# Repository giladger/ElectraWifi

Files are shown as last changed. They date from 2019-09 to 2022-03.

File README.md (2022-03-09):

# ElectraWifi
This project intends to replace a plain Electra AC IR receiver with an ESP8266 to give it wifi capabilities and control it over MQTT.

## Description
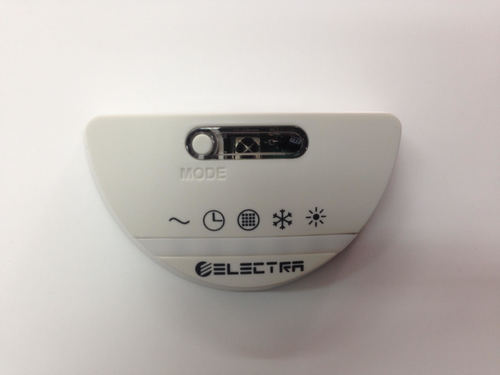
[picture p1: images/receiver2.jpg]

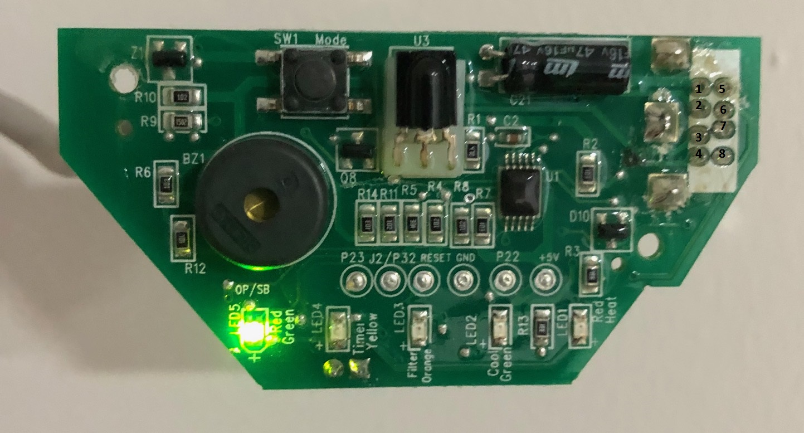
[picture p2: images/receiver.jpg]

The original receiver itself is "dumb" and doesn't hold any state and all the interaction is handled by the main unit, this makes it expandable so it can easily be replaced by an ESP8266.

The receiver is connected to the main unit with an 8-pin mini din connector, with the following pins:

1. 5V
2. Heat LED
3. IR signal
4. Green power LED (LOW for on)
5. Timer LED
6. Beep
7. Button
8. Cool LED

So now all we need to do is throw out the old receiver and hook up an ESP8266 to the pins 1, 3, 4.

## Prerequisites
### Hardware
First you would need:
- ESP8266 (ESP32 would also work)
- 1 NPN transistor
- 2 1kΩ resistors
- A breadboard/PCB
- IR receiver (optional)

Hook everything up according to the following schematic:
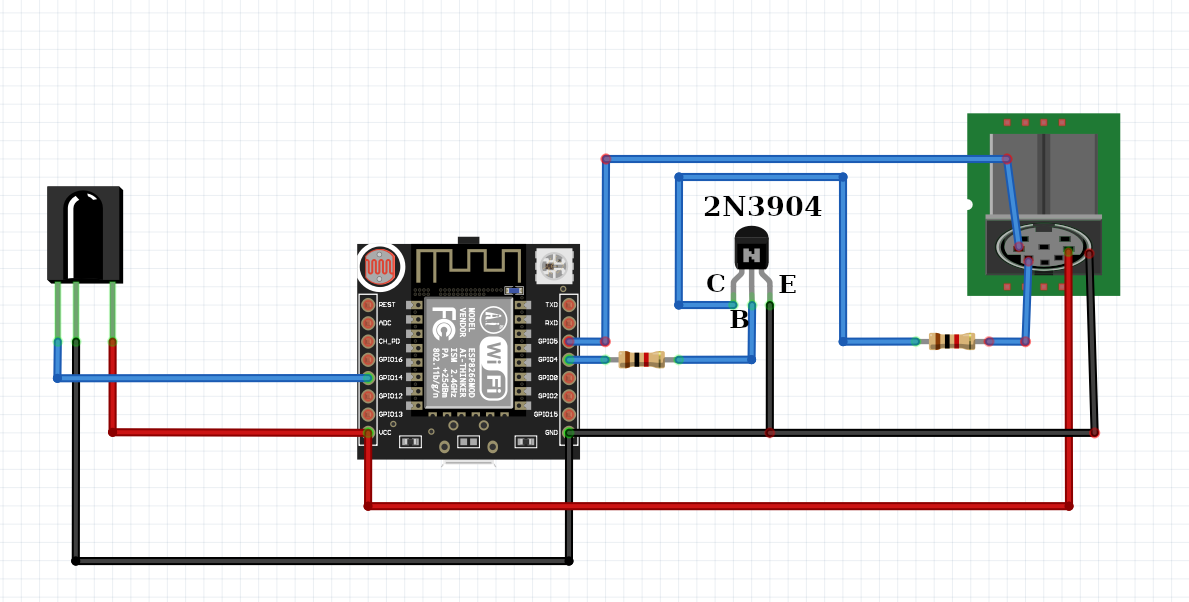
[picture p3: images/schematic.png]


To use the code as-is, use GPIO4 for IR send, GPIO5 for power state input and GPIO14 for IR recv (optional).

### Software
The code in this repo is based on [Homie](https://github.com/homieiot/homie-esp8266) for MQTT handling and for OTA.
Please follow the instructions there to install all the dependencies.

Once the code is installed on the esp, it will boot in configuration mode. Follow the instructions [here](https://homieiot.github.io/homie-esp8266/docs/2.0.0/configuration/json-configuration-file/) to upload a JSON configuration file.

A sample json config file is provided under `/data/homie/config.json`. This file can be edited and uploaded using platform.io under "Platform -> Build Filesystem Image" and the "Platform -> Upload Filesystem Image". Make sure to properly edit the file before uploading.

### Building
Building with platform.io is quite simple. But Homie is not compatible with Platform.io 3.0 for ESP8266 out of the box. You need to change two files in the Homie library.
- Start building as usual. You will see some errors regarding the "HTTPClient" calls not being supported.
- Navigate to the ./pio/libdeps/<target>/Homie/src/Homie/Boot
- Edit the `BootConfig.hpp` and `BootConfig.cpp` files as follows:

- BootConfig.hpp
Add the following line:
```
  WiFiClient _wifiClient;
```
So that the file looks as follows:
```
 private:
  AsyncWebServer _http;
  WiFiClient _wifiClient;
  HTTPClient _httpClient;
  DNSServer _dns;
```

- BootConfig.cpp
Replace the following line:
```
  _httpClient.begin(url);
```
so that it looks as follows:
```
  // send request to destination (as in incoming host header)
  _httpClient.setUserAgent(F("ESP8266-Homie"));
  _httpClient.begin(_wifiClient,url);
  // copy headers
```

## Usage
After the esp is configured, it will subscribe to the following MQTT topics:
- .../state/json/set 
  - This topic accepts a json in the following format (all fields are mandatory), updates the state and send it to the AC unit:   
  `{"power": "on|off", "mode": "cool|heat|fan|dry|auto", "fan": "low|med|high|auto", "temperature": 15..30, "ifeel": "on|off", "swing":"on|off|hor|both"}`
- .../ifeel_temperature/state/set
  - This topic accepts a number between 5 and 36 and sends it to the main unit as a temperature received by the "i feel" function of the remote.
  
Monitoring and getting the real state of the AC is also possible by subscribing to the following topics:
- .../power/state
- .../mode/state
- .../fan/state
- .../temperature/state
- .../ifeel/state
- .../swing/state

### Home Assistant

Home Assistant's MQTT HVAC component can be used with the following configuration:

```yaml
climate:
  - platform: mqtt
    name: AC
    modes:
      - "heat"
      - "cool"
      - "dry"
      - "off"
    fan_modes:
      - "high"
      - "med"
      - "low"
      - "auto"
    swing_modes:
      - "off"
      - "on"
      - "hor"
      - "both"
    min_temp: 16
    max_temp: 30
    power_command_topic: "devices/AC/power/state/set"
    payload_on: "on"
    payload_off: "off"
    mode_command_topic: "devices/AC/mode/state/set"
    mode_state_topic: "devices/AC/mode/state"
    temperature_command_topic: "devices/AC/temperature/state/set"
    temperature_state_topic: "devices/AC/temperature/state"
    fan_mode_command_topic: "devices/AC/fan/state/set"
    fan_mode_state_topic: "devices/AC/fan/state"
    swing_mode_command_topic: "devices/AC/swing/state/set"
    swing_mode_state_topic: "devices/AC/swing/state"
```

It's possible to activate the iFeel by using the build-in aux-heat or away_mode topic for the MQTT HVAC component by adding the following lines:
Its not ideal as it will show "Preset: Home/Away" but it works fine.

```yaml
climate:
    ...
    ...
    away_mode_command_topic: "devices/AC/ifeel/state/set"
    away_mode_state_topic: "devices/AC/ifeel/state"
```

### Home Assistant - Lovelace UI

Lovelace UI example:

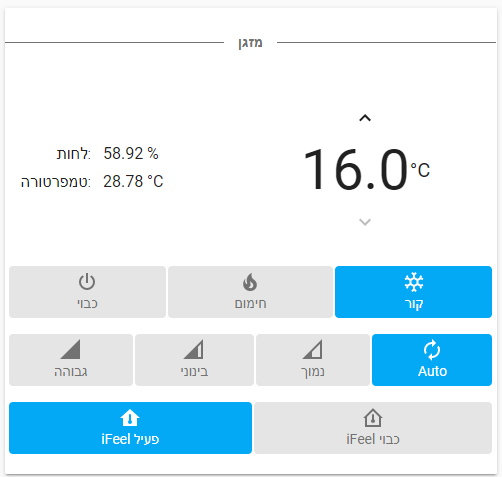
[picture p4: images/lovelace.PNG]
Lovelace UI Example


Home Assistant's MQTT HVAC component can be used with the following configuration (note the use if simple-thermostat custom component):

```yaml
cards:
  - type: custom:simple-thermostat
    entity: climate.ac
    name: false
    step_size: 1
    control:
      _headings: false
      hvac:
        'off':
          icon: mdi:power
          name: 'כבוי'
        cool:
          icon: mdi:snowflake
          name: 'קור'
        heat:
          icon: mdi:fire
          name: 'חימום'
        dry: false
      fan:
        'low':
          icon: mdi:network-strength-1
          name: 'נמוך'
        'med':
          icon: mdi:network-strength-3
          name: 'בינוני'
        'high':
          icon: mdi:network-strength-4
          name: 'גבוהה'
        'Auto':
          icon: mdi:autorenew
          name: 'אוטו'
      swing:
        'on':
          icon: mdi:home-thermometer
          name: 'iFeel פעיל'
        'off':
          icon: mdi:home-thermometer-outline
          name: 'iFeel כבוי'
    sensors:
      - entity: sensor.<external-hunidity-sensor>
        name: 'לחות'
      - entity: sensor.<external-temperature-sensor>
        name: 'טמפרטורה'
    hide:
      mode: false
      temperature: true
```

### Home Assistant - iFeel update based to external sensor

To Inject external temperature (from any tempureture sensor) to iFeel every minute, add the following automation:

```yaml
automation:
  - alias: Update ifeel temperature
    initial_state: 'on'
    trigger:
      platform: time_pattern
      minutes: "/1"
    action:
      service: mqtt.publish
      data:
        topic: "homie/<homie-id>/ifeel_temperature/state/set"
        payload_template: "{{ states.sensor.<my-tempereture-sensor>.state }}"
```

### Credits

Many thanks to @barakwei and [IRelectra](https://github.com/barakwei/IRelectra) for analyzing the IR protocol.

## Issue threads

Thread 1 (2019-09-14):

How to use this repo?

ohadlevy, 2019-09-14:
Would it be possible to include more details, e.g:

- [ ] List of required hardware
- [ ] Wiring diagrams and pictures
- [ ] Instruction on how to run this code? (e.g. do you use it with tasmota? mqtt etc?)
- [ ] MQTT example usage (e.g. from Home Assistant)

Thanks!

ohadlevy, 2019-09-15:
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

ohadlevy, 2019-09-16:
fixed in 19be57b5ac582c7986c7a57b0c75368577003277

guysoft, 2021-12-26:
Hey, ia there a picture or documentation how its all connected when complete?  The diagram here and in the main readme shows a ps/2-like connector which I don't seem to see on the unit

giladger, 2021-12-27:
@guysoft the connector is located at the back of this receiver unit
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

guysoft, 2021-12-27:
I can't seem to be able to take it apart. I can see a small plastic bit at the bottom, but it wont pry open when I push it. Nor can I see how its mounted to the wall

giladger, 2021-12-27:
@guysoft there should be 2 snaps at the top

guysoft, 2021-12-28:
Indeed,
Ordered the 8-pin mini din connector so I can solder it to the epsp8266 and hope to get it working :)
Here is a photo for reference:
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

And the cable.
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

guysoft, 2022-02-23:
Hey,
The schismatic seems to be wrong in two ways:
1. the 8-pin mini din connector data connections need to be reversed
2. The transistor  pins are not labeled. and are location varies between transistors, I used a 2N3904 where the emitter and collector are reversed.

Here is the schematic that worked for me:
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

I think this is the correct one since ariel also confirmed this is the setup that worked for him.

I can PR with the fritzing source and this image if you would like @giladger

ohadlevy, 2022-02-24:
I will try it out and also report, I wants able to get it working using the prior instructions too.

guysoft, 2022-02-24:
@ohadlevy After examining the schematic you posted here: https://github.com/giladger/ElectraWifi/issues/1#issuecomment-531544766
The connection to the 8-pin mini din connector is the same as I posted in the schematic I draw. The pin on the AC connector is revered in the one on the git repo currently at: https://github.com/giladger/ElectraWifi/commit/9a471f13f8288fb0cb70ad381657349ce7e8398a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
So it looks like we have something the same :)

I can't tell which type of NPN transistor you used, and their pinout is different, I labeled mine so its easier to translate to other parts.

guysoft, 2022-03-03:
Ok, I guess I better pr the schematic then. that's 3 people it works for

Closed 2019-09-16.

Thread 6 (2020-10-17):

Newer models as well?

adizag, 2020-10-17:

idomp, 2020-10-18:
Hi,
You should open up the plastic case and upload some pictures of the PCB inside.

Note that it looks like it have a WIFI symbol in the right top corner - if so I doubt that ElectaWifi will work.

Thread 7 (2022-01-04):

fix for esp32 nodemcu v3 Arduino Lolin Homie compile error

tomergam, 2022-01-04:
use this fix for using esp32  nodemcu v3 Arduino Lolin compile error Homie v2.0.0
source:
https://issueexplorer.com/issue/homieiot/homie-esp8266/711

` the fix is to add WiFiClient _wifiClient; to the class in BootConfig.hpp and then fix the call (_httpClient.begin(_wifiClient, url);)`

garci66, 2022-01-06:
I just added the same comment on a PR and readme so that in can compile with Homie v3.0.1.

Also added some changes to it to support ArduinoJson 6 and now ill issue a new PR with support for ESP01

tomergam, 2022-01-11:
Thanks @garci66
it is possible to upload image OTA?
not able with PlatformIO

guysoft, 2022-03-12:
I think this is fixed now. Also CI confirms it.

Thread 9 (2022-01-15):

[debug] It seems like MQTT works, but is not activating the AC

guysoft, 2022-01-15:
Hey,

Is there a way to figure out what is not working on the AC side?

I built the board as shown in the instructions and flashed firmware.bin, but it seems like sending messages does not activate the AC.
Send over mqtt at ``devices/ac/state/json/set`` for example does get received:
```json
{"power": "on", "mode": "heat", "fan": "med", "temperature": 24, "ifeel": "off"}
```
And I can see that ``devices/ac/temperature/state`` gets updated with the correct temprature. However the AC does not power on.

Attaching the message broker output just to confirm the esp8266 communication works
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

giladger, 2022-01-16:
@guysoft Feel free to message me on https://www.facebook.com/giladger/ and I'll try to assist

Closed 2022-01-16.

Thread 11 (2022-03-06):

Heating and dry modes don't work, cooling and fan does

guysoft, 2022-03-06:
Hey,
So I have now ElectraWifi set up and working. However, when I send a heat.

Steps to reproduce:
1. test that it works, send to ``devices/ac/state/json/set`` (or the path you set in the homie setup):
```json
{"power": "on", "mode": "cool", "fan": "high", "temperature": 25, "ifeel": "off"}
```
See that you can change power on and off and switch the AC on and off.
2. Try to send now:
```json
{"power": "on", "mode": "heat", "fan": "high", "temperature": 25, "ifeel": "off"}
```
Expected:
AC should heat.
Actual:
Does not switch on.

Electra remote type: RC-3 (or RC3 sold as too)

guysoft, 2022-03-07:
Looking at the code I am suspecting it might be a timing issue.
The only difference between heat and dry, and the rest is they don't have a one at the end (auto also works).

work:
```
    MODE_COOL = 0b001,
    MODE_FAN = 0b101,
    MODE_AUTO = 0b011,
```
Done work:
```
    MODE_HEAT = 0b010,
    MODE_DRY = 0b100,
```

https://github.com/giladger/ElectraWifi/blob/master/src/IRelectra.h#L22

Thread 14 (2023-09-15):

Can the transistor in the circuit be removed?

itay7564, 2023-09-15:
Hello there, nice project!
In the circuit, when the output GPIO goes HIGH, the transistor pulls the IR pin down to GND through a 1K resistror
when the output is LOW, the transistor is in high impedance, and likely the IR pin is pushed up to 5V by an internal pullup in the AC

However, the esp can also pull the IR pin to GND directly (through a 1K resistor)
and instead of using a transistor, to go high impedence directly from the esp, we can set the output pin to "input".

So the code would change **from:**
Initializer:
`pinMode(output_pin, INPUT); // GPIO is an output`
Low output:
`digitalWrite(output_pin, HIGH); // IR output pulled to 0V by transistor`
High output:
`digitalWrite(output_pin, LOW); // IR output pushed to 5V by pullup`

**To:**
initializer:
`digitalWrite(output_pin, LOW); // Always have a LOW output`
Low output:
`pinMode(output_pin, OUTPUT); // IR output pulled to 0V by pin sourcing current`
Hight output:
`pinMode(output_pin, INPUT); // GPIO goes high-z and IR output pushed to 5V by pullup`

The circuit would change to just a 1K resistor between the GPIO to the IR output, instead of the transistor and two resistors.

(Maybe I have missed something about this circuit, tell me if I'm wrong)

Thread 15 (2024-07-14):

8-pin mini din connector seems to be wrong in the schematics

tomer-w, 2024-07-14:
The actual pin in the unit is 3-3-2 pins (from the top):
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
Here is a drawing I found which show them better. Each row has all the pins in the same height.
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
In the readme file it seems the opposite - 2-3-3 and the pins height in each row is different:
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
Can you verify which pins should I use? Hopefully to use better schematics which is aligned with the actual connector?

tomer-w, 2024-07-20:
Using a continuity tester, I verified the mapping between the numbers on the circuit and the ones I have on the plug drawing. It would be great to align them on the official readme.

<html xmlns:o="urn:schemas-microsoft-com:office:office"
xmlns:dt="uuid:C2F41010-65B3-11d1-A29F-00AA00C14882"
xmlns="http://www.w3.org/TR/REC-html40">

<head>

<meta name=ProgId content=OneNote.File>
<meta name=Generator content="Microsoft OneNote 15">
</head>

<body lang=en-IL style='font-family:Calibri;font-size:11.0pt'>
<!--StartFragment-->

<div style='direction:ltr'>

Description | Circuit   ID | Plug ID
-- | -- | --
5V | 1 | 3
Heat LED | 2 | 1
IR signal | 3 | 2
Green power LED (LOW for on) | 4 | 5
Timer LED | 5 | 6
Beep | 6 | 4
Button | 7 | 7
Cool LED | 8 | 8
Ground | Shield | Shield

</div>

<!--EndFragment-->
</body>

</html>

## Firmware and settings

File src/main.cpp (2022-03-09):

#include <Homie.h>
#include <Arduino.h>
#include <WiFiUdp.h>
#include <string>
#include <IRremoteESP8266.h>
#include <IRrecv.h>
#include <ArduinoJson.h>
#include "IRelectra.h"


HomieNode temperatureNode("temperature", "temperature","temperature");
HomieNode modeNode("mode", "mode","mode");
HomieNode fanNode("fan", "fan","fan");
HomieNode swingNode("swing", "swing","swing");
HomieNode ifeelNode("ifeel", "ifeel","ifeel");
HomieNode ifeelTempNode("ifeel_temperature", "ifeel_temperature","ifeel_temperature");
HomieNode powerNode("power", "power","power");
HomieNode stateNode("state", "state","state");

#ifdef ARDUINO_ESP8266_ESP01
const uint8_t POWER_PIN = 2;
const uint8_t IR_PIN = 0;
#else
const uint8_t POWER_PIN = 5;
const uint8_t IR_PIN = 4;
const uint8_t GREEN_LED_PIN = 12;
const uint8_t RED_LED_PIN = 15;
#endif

#ifndef ELECTRAWIFI_NO_IR_RCV
const uint8_t IR_RECV_PIN = 14;
#endif

const uint8_t kTimeout = 10;
const uint16_t kCaptureBufferSize = 300;

WiFiUDP udpClient;
IRelectra ac(IR_PIN);

#ifndef ELECTRAWIFI_NO_IR_RCV
IRrecv irrecv(IR_RECV_PIN, kCaptureBufferSize, kTimeout, true);
decode_results ir_ticks;
#endif

const int IFEEL_INTERVAL = 2 * 60000; // 2 min
const int POWER_DEBOUNCE = 2000; // 2 sec
const int UPDATES_INTERVAL = 10 * 60000; // 10 min
ulong power_change_time = 0;
ulong ifeel_send_time = 0;
ulong updates_send_time = 0;


void send_updates() {
  String fan, mode, swing;
  if (ac.fan == FAN_LOW) {
    fan = "low";
  } else if (ac.fan == FAN_MED) {
    fan = "med";
  } else if (ac.fan == FAN_HIGH) {
    fan = "high";
  } else if (ac.fan == FAN_AUTO) {
    fan = "auto";
  } 
  
  ac.power_real = ac.power_setting;

  if (ac.power_real) {
    if (ac.mode == MODE_COOL) {
      mode = "cool";
    } else if (ac.mode == MODE_HEAT) {
      mode = "heat";
    } else if (ac.mode == MODE_DRY) {
      mode = "dry";
    } else if (ac.mode == MODE_AUTO) {
      mode = "auto";
    }
  }
  else {
    mode = "off";
  }

  if (ac.swing == SWING_ON && ac.swing_h == SWING_H_ON) {
    swing = "both";
  } else if (ac.swing == SWING_ON && ac.swing_h == SWING_H_OFF) {
    swing = "on";
  } else if (ac.swing == SWING_OFF && ac.swing_h == SWING_H_ON) {
    swing = "hor";
  } else {
    swing = "off";
  }
  //Serial << "AC swing: " << (ac.swing ? "on": "off") << "|" << (ac.swing_h  ? "on": "off") <<endl;
  //Serial << "Send Update swing: " << swing << endl;
  powerNode.setProperty("state").send(ac.power_real ? "on": "off");
  fanNode.setProperty("state").send(fan);
  modeNode.setProperty("state").send(mode);
  swingNode.setProperty("state").send(swing);
  temperatureNode.setProperty("state").send(String(ac.temperature));
  ifeelNode.setProperty("state").send(ac.ifeel == IFEEL_ON ? "on" : "off");
}

void loopHandler() {
  ulong now = millis();

  // Set power led and update the power state after it's stable for a while
  uint power_state = !digitalRead(POWER_PIN);
#ifndef ARDUINO_ESP8266_ESP01
  digitalWrite(GREEN_LED_PIN, power_state);
#endif
  if (power_state != ac.power_real) {
    if (power_change_time) {
      if (now - power_change_time > POWER_DEBOUNCE) {
        ac.power_real = power_state;
        ac.power_setting = power_state;
        powerNode.setProperty("state").send(power_state ? "on": "off");
        power_change_time = 0;
      }
    } else {
      power_change_time = now;
    }
  } else {
    power_change_time = 0;
  }

  // Send ifeel if relevant
  if (now - ifeel_send_time >= IFEEL_INTERVAL) {
    if (ac.ifeel == IFEEL_ON) {
      ac.SendElectra(true);
    }
    ifeel_send_time = now;
  }

  // Send updates
  /*
  if (now - updates_send_time >= UPDATES_INTERVAL) {
    send_updates();
    updates_send_time = now;
  }
  */

  // Handle IR recv
#ifndef ELECTRAWIFI_NO_IR_RCV
  if (irrecv.decode(&ir_ticks)) {
    uint64_t code = 0;
    code = DecodeElectraIR(ir_ticks);
    irrecv.resume();
    if (code) {
      ac.UpdateFromIR(code);
      ac.SendElectra(false);
      send_updates();
    }
  }
#endif
}


bool temperatureHandler(const HomieRange& range, const String& value) {
  uint8_t temp = value.toInt();
  if (temp < 15 || temp > 30) { // setpoint temp has only 4 bits where 15 == 0b0000 and 30 == 0b1111
    return false;
  }
  ac.temperature = temp;
  ac.SendElectra(false);
  send_updates();
  return true;
}

bool modeHandler(const HomieRange& range, const String& value) {
  if (value == "cool") {
    ac.mode = MODE_COOL;
  } else if (value == "heat") {
    ac.mode = MODE_HEAT;
  } else if (value == "auto") {
    ac.mode = MODE_AUTO;
  } else if (value == "dry") {
    ac.mode = MODE_DRY;
  } else if (value == "fan") {
    ac.mode = MODE_FAN;
  } else {
    return false;
  }
  ac.SendElectra(false);
  send_updates();
  return true;
}

bool fanHandler(const HomieRange& range, const String& value) {
  if (value == "low") {
    ac.fan = FAN_LOW;
  } else if (value == "med") {
    ac.fan = FAN_MED;
  } else if (value == "high") {
    ac.fan = FAN_HIGH;
  } else if (value == "auto") {
    ac.fan = FAN_AUTO;
  } else {
    return false;
  }
  ac.SendElectra(false);
  send_updates();
  return true;
}

bool ifeelHandler(const HomieRange& range, const String& value) {
  if (value == "on") {
    ac.ifeel = IFEEL_ON;
  } else if (value == "off") {
    ac.ifeel = IFEEL_OFF;
  } else {
    return false;
  }
  ac.SendElectra(false);
  send_updates();
  return true;
}

bool ifeelTempHandler(const HomieRange& range, const String& value) {
  uint8_t temp = value.toInt();
  if (temp < 5 || temp > 36) { // ifeel temp has only 5 bits where 0 == 0b00000 and 36 == 0b11111
    return false;
  }
  ac.ifeel_temperature = temp;
  send_updates();
  return true;
}

bool swingHandler(const HomieRange& range, const String& value) {
  //Serial << "Swing Handler value: " << value << endl;
  if (value == "on") {
    ac.swing = SWING_ON;
    ac.swing_h = SWING_H_OFF;
  } else if (value == "both") {
    ac.swing = SWING_ON;
    ac.swing_h = SWING_H_ON;
  } else if (value == "hor") {
    ac.swing = SWING_OFF;
    ac.swing_h = SWING_H_ON;
  }  else if (value == "off"){
    ac.swing = SWING_OFF;
    ac.swing_h = SWING_H_OFF;
  } else {
    return false;
  }
  ac.SendElectra(false);
  send_updates();
  return true;
}

bool powerHandler(const HomieRange& range, const String& value) {
  if (value == "on") {
    ac.power_setting = true;
  } else if (value == "off") {
    ac.power_setting = false;
  } else {
    return false;
  }
  ac.SendElectra(false);
  ac.power_real = ac.power_setting;
  powerNode.setProperty("state").send(ac.power_real ? "on": "off");
  send_updates();
  return true;
}

bool jsonHandler(const HomieRange& range, const String& value) {
  StaticJsonDocument<200> parsed;
  auto error = deserializeJson(parsed,value);
  if (error) {
    return false;
  }

  String fan = parsed["fan"];
  String mode = parsed["mode"];
  String power = parsed["power"];
  String ifeel = parsed["ifeel"];
  String temp_str = parsed["temperature"];
  String swing = parsed["swing"];
  uint8_t temp = temp_str.toInt();

  if (mode == "cool") {
    ac.mode = MODE_COOL;
  } else if (mode == "heat") {
    ac.mode = MODE_HEAT;
  } else if (mode == "auto") {
    ac.mode = MODE_AUTO;
  } else if (mode == "dry") {
    ac.mode = MODE_DRY;
  } else if (mode == "fan") {
    ac.mode = MODE_FAN;
  } else {
    return false;
  }

  if (fan == "low") {
    ac.fan = FAN_LOW;
  } else if (fan == "med") {
    ac.fan = FAN_MED;
  } else if (fan == "high") {
    ac.fan = FAN_HIGH;
  } else if (fan == "auto") {
    ac.fan = FAN_AUTO;
  } else {
    return false;
  }

  if (power == "on") {
    ac.power_setting = true;
  } else if (power == "off") {
    ac.power_setting = false;
  } else {
    return false;
  }

  if (swing == "on") {
    ac.swing = SWING_ON;
    ac.swing_h = SWING_H_OFF;
  } else if (swing == "both") {
    ac.swing = SWING_ON;
    ac.swing_h = SWING_H_ON;
  } else if (swing == "hor") {
    ac.swing = SWING_OFF;
    ac.swing_h = SWING_H_ON;
  }  else if (swing == "off") {
    ac.swing = SWING_OFF;
    ac.swing_h = SWING_H_OFF;
  } else {
    return false;
  }

  if (ifeel == "on") {
    ac.ifeel = IFEEL_ON;
  } else if (ifeel == "off") {
    ac.ifeel = IFEEL_OFF;
  } else {
    return false;
  }

  if (temp < 15 || temp > 30) { // setpoint temp has only 4 bits where 15 == 0b0000 and 30 == 0b1111
    return false;
  }
  ac.temperature = temp;

  ac.SendElectra(false);
  ac.power_real = ac.power_setting;

  send_updates();
  return true;
}

void setup() {
  Serial.begin(115200);
  Serial << endl << endl;
  //Homie.disableLogging();
#ifdef ARDUINO_ESP8266_ESP01
  Homie.disableLedFeedback();
#endif
  Homie_setFirmware("ElectraWifi", "1.0.0");
  Homie.setLoopFunction(loopHandler);
  temperatureNode.advertise("state").settable(temperatureHandler);
  fanNode.advertise("state").settable(fanHandler);
  modeNode.advertise("state").settable(modeHandler);
  ifeelNode.advertise("state").settable(ifeelHandler);
  ifeelTempNode.advertise("state").settable(ifeelTempHandler);
  powerNode.advertise("state").settable(powerHandler);
  swingNode.advertise("state").settable(swingHandler);
  stateNode.advertise("json").settable(jsonHandler);
  
  pinMode(POWER_PIN, INPUT_PULLUP);
#ifndef ARDUINO_ESP8266_ESP01
  pinMode(GREEN_LED_PIN, OUTPUT);
  Homie.setLedPin(RED_LED_PIN, HIGH);
#endif
#ifndef ELECTRAWIFI_NO_IR_RCV
  irrecv.setUnknownThreshold(100); 
  irrecv.enableIRIn();
#endif
  Homie.setup();
}

void loop() {
  Homie.loop();
}

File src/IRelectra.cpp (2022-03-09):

/*
 * Based on IRelectra (https://github.com/barakwei/IRelectra) by Barak Weiss
 */

#include "IRelectra.h"
#include <stdint.h>
#include <Arduino.h>
#include <IRutils.h>

#define UNIT 1000
#define TICKS_TO_UNITS(x) round((float)(x) * kRawTick / UNIT)

#define NUM_BITS 34

IRelectra::IRelectra(uint8_t output_pin) : output_pin(output_pin)
{
    pinMode(output_pin, OUTPUT);
    power_setting = POWER_KEEP;
    power_real = false;
    mode = MODE_COOL;
    fan = FAN_LOW;
    temperature = 26;
    swing_h = SWING_H_OFF;
    swing = SWING_OFF;
    sleep = SLEEP_OFF;
    ifeel_temperature = 0;
    ifeel = IFEEL_OFF;
}

// Add bit b to array p at index i
// This function is used to convert manchester encoding to MARKs and SPACEs
// p is the pointer to the start of the MARK, SPACE array
// i is the current index
// b is the bit we want to add to the MARK, SPACE array
// A zero bit is one unit MARK and one unit SPACE
// a one bit is one unit SPACE and one unit MARK
void IRelectra::addBit(unsigned int* p, int* i, char b) {
    if (((*i) & 1) == 1) {
        // current index is SPACE
        if ((b & 1) == 1) {
            // one is one unit low, then one unit up
            // since we're pointing at SPACE, we should increase it byte a unit
            // then add another MARK unit
            *(p+*i) += UNIT;
            (*i)++;
            *(p+*i) = UNIT;
        }
        if ((b & 1) == 0) {
            // we need a MARK unit, then SPACE unit
            (*i)++;
            *(p+*i) = UNIT;
            (*i)++;
            *(p+*i) = UNIT;
        }
    } else if (((*i) & 1) == 0) {
        // current index is MARK
        if ((b & 1) == 1) {
            (*i)++;
            *(p+*i) = UNIT;
            (*i)++;
            *(p+*i) = UNIT;
        }
        if ((b & 1) == 0) {
            *(p+*i) += UNIT;
            (*i)++;
            *(p+*i) = UNIT;
        }
    }

}

// Sends the specified configuration to the IR led using IRremote
// 1. Get the numeric value of the configuration
// 2. Convert to IRremote compatible array (MARKS and SPACES)
// 3. Send to GPIO
void IRelectra::SendElectra(bool notify) {
    uint data[200]; //~maximum size of the IR packet
    int i = 0;
 
    // get the data representing the configuration
    uint64_t code = EncodeElectra(notify);
    
    // The whole packet looks this:
    //  3 Times: 
    //    3000 usec MARK
    //    3000 used SPACE
    //    Maxchester encoding of the data, clock is ~1000usec
    // 4000 usec MARK
    for (int k = 0; k<3; k++) {
        data[i] = 3 * UNIT; //mark
        i++;
        data[i] = 3 * UNIT;
        for (int j = NUM_BITS - 1; j >= 0; j--) {
            addBit(data, &i, (code >> j) & 1);
        }
        i++;
    }
    data[i] = 4 * UNIT;

    SendRaw(data, i + 1);
}

void IRelectra::SendRaw(unsigned int *data, uint size) {
    for (uint i = 0; i < size; ++i) {
        digitalWrite(output_pin, (i % 2) ? LOW : HIGH);
        delayMicroseconds(data[i]);
    }
    digitalWrite(output_pin, LOW);
}


// Encodes specific A/C configuration to a number that describes
// That configuration has a total of 34 bits
//    33: Power bit, if this bit is ON, the A/C will toggle it's power.
// 32-30: Mode - Cool, heat etc.
// 29-28: Fan - Low, medium etc.
//    27: Temperature notification (used in I Feel)
//    26: Horizontal Swing On/Off
//    25: Swing On/Off
//    24: Set I Feel
// 23-19: Temperature, 4 bits for set (where 15 is 00000, 30 is 01111), 5 bits for notify
//    18: Sleep mode On/Off
// 17- 2: Zeros
//     1: One
//     0: Zero
uint64_t IRelectra::EncodeElectra(bool notify) {
    uint64_t code = 0;
    uint32_t send_temp;
    power_t power;

    if (power_setting == power_real) {
        power = POWER_KEEP;
    } else {
        power = POWER_TOGGLE;
    }

    if (notify) {
        send_temp = ifeel_temperature - 5;
    } else {
        send_temp = temperature - 15;
    }
    code |= (((uint64_t)power     & 1)  << 33);
    code |= (((uint64_t)mode      & 7)  << 30);
    code |= (((uint64_t)fan       & 3)  << 28);
    code |= (((uint64_t)notify    & 1)  << 27);
    code |= (((uint64_t)swing_h   & 1)  << 26);
    code |= (((uint64_t)swing     & 1)  << 25);
    code |= (((uint64_t)ifeel     & 1)  << 24);
    code |= (((uint64_t)send_temp & 31) << 19);
    code |= (((uint64_t)sleep     & 1)  << 18);
    code |= 2;
    
    return code;
}

void IRelectra::UpdateFromIR(uint64_t code) {
    uint32_t send_temp;
    power_t power;
    bool notify;

    power =     (power_t)  ((code >> 33) & 1);
    mode =      (ac_mode_t)((code >> 30) & 7);
    fan =       (fan_t)    ((code >> 28) & 3);
    notify =    (bool)     ((code >> 27) & 1);
    swing_h =   (swing_h_t)((code >> 26) & 1);
    swing =     (swing_t)  ((code >> 25) & 1);
    ifeel =     (ifeel_t)  ((code >> 24) & 1);
    send_temp = (ifeel_t)  ((code >> 19) & 31);
    sleep =     (sleep_t)  ((code >> 18) & 1);

    if (power == POWER_TOGGLE) {
        power_setting = !power_real;
    } 

    if (notify) {
        ifeel_temperature = send_temp + 5;
    } else {
        temperature = send_temp + 15;
    }
}


uint64_t manchester_to_bits(volatile uint16_t *data, uint8_t &i, uint8_t size, bool is_space) {
    uint64_t result = 0;
    while (i < size - 1) {
        if (TICKS_TO_UNITS(data[i]) == 1) {
            if (TICKS_TO_UNITS(data[i + 1]) > 0) {
                result = result << 1 | (is_space ? 1 : 0);
                if (TICKS_TO_UNITS(data[i + 1]) > 1) {
                    data[i + 1] -= UNIT / kRawTick;
                    is_space = !is_space;
                    i += 1;
                    continue;
                }
                i += 2;
                continue;
            }
            return 0;
        }
        if (TICKS_TO_UNITS(data[i]) == 3) {  // the beginning to the next repetition
            return result;
        }
        return 0;
    }
    if (TICKS_TO_UNITS(data[i]) == 4) { // the end of the last repetition
        return result;
    }

    return 0;
}
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

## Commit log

2019-09-16 notifiy power change optimistically
2019-09-16 pull up power state pin
2020-08-07 added "auto" mode to fan speed type (received)
2022-03-06 Fix schematic according to https://github.com/giladger/ElectraWifi/issues/1#issuecomment-1049118923
    [schematic.fzz]
2022-03-09 add support for conditional pin numbers
2022-03-09 Add copy of artifacts and some emojis 😊
